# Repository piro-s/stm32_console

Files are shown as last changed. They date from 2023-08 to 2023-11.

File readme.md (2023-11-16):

## STM32 Console  
At the beginning it was a game console project on STM32, but then I found out 
about Anbernic devices. Now this is a debugging device for STM32F103Cx 
microcontrollers (STM32F103C6, C8, CB, maybe C4, but too little memory).  
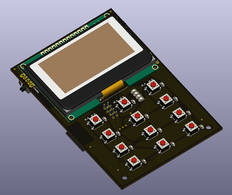
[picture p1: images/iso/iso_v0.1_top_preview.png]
iso_v0.1_top
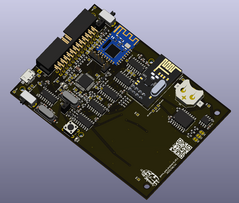
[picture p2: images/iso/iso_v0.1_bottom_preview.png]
iso_v0.1_bottom
   

---
The console has:  
+ display;  
+ buttons;  
+ temperature sensor LM75B;  
+ RTC module DS3231M;  
+ 4 LEDs;  
+ vibration motor;  
+ external speaker;  
+ radio module NRF24L01;  
+ bluetooth module JDY-23;  
+ interface converters: RS-232, RS-485 (with terminator 120 Ohm), USB-UART.  

---
The external connector gives access to connect:  
+ 4 digital inputs/outputs;  
+ 2 PWM outputs;  
+ 1 analog input (max 6V, if you need more, connect a resistor in series, see the scheme for details);  
+ SPI, I2C, UART;  
+ RS-232, RS-485.  

Pinout (IDC-26M):  
| Pin | Name | Description |
|-----|---|---|
| 1 | 5V | Output from TP5400 |
| 2 | Vdd | From usb or for power input |
| 3 | 3.3V | Output from AMS1117 |
| 4 | 5V | Output from TP5400 |
| 5 | Analog input  | Max 6V, or use resistor for increase voltage divider |
| 6 | PWM2 | PWM output or GPIO PORTB.9, limited 1k Ohm |
| 7 | GPIO PORTA.12 | Limited 1k Ohm |
| 8 | PWM1 | PWM output or GPIO PORTB.8, limited 1k Ohm |
| 9 | GPIO PORTA.11 | Limited 1k Ohm |
| 10  | SPI CS | To connect an external device or GPIO PORTB.12, limited 1k Ohm |
| 11  | GPIO PORTA.10 | Limited 1k Ohm |
| 12  | SPI MOSI | |
| 13  | GPIO PORTA.9  | Limited 1k Ohm |
| 14  | SPI SCK | |
| 15  | SPI MISO | |
| 16  | Data+ | Noninverting Receiver Input A / Driver Output A (for MOXA Data-) |
| 17  | I2C SCL | |
| 18  | Data- | Inverting Receiver Input B / Driver Output B (for MOXA Data+) |
| 19  | I2C SDA | |
| 20  | GND | |
| 21  | UART RX | Also connect to driver RS-485 and USB |
| 22  | UART TX | Also connect to driver RS-485 and USB |
| 23  | RS-232 RX | |
| 24  | RS-232 TX | |
| 25  | GND | |
| 26  | GND | |

---
#### Scheme:  
[Scheme_v0.1](docs/game_pad_keyboard_v0.1.pdf)  

#### PCB:  
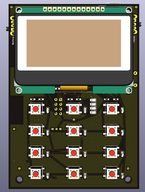
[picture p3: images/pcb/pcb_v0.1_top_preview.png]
pcb_v0.1_top
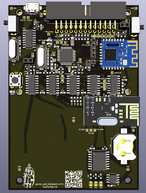
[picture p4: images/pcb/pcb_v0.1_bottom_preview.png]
pcb_v0.1_bottom
   

#### Gerber:  
Archive for production:  
[gerber_v0.1](https://github.com/piro-s/stm32_console/raw/master/gerber/game_pad_keyboard_v0.1.zip)

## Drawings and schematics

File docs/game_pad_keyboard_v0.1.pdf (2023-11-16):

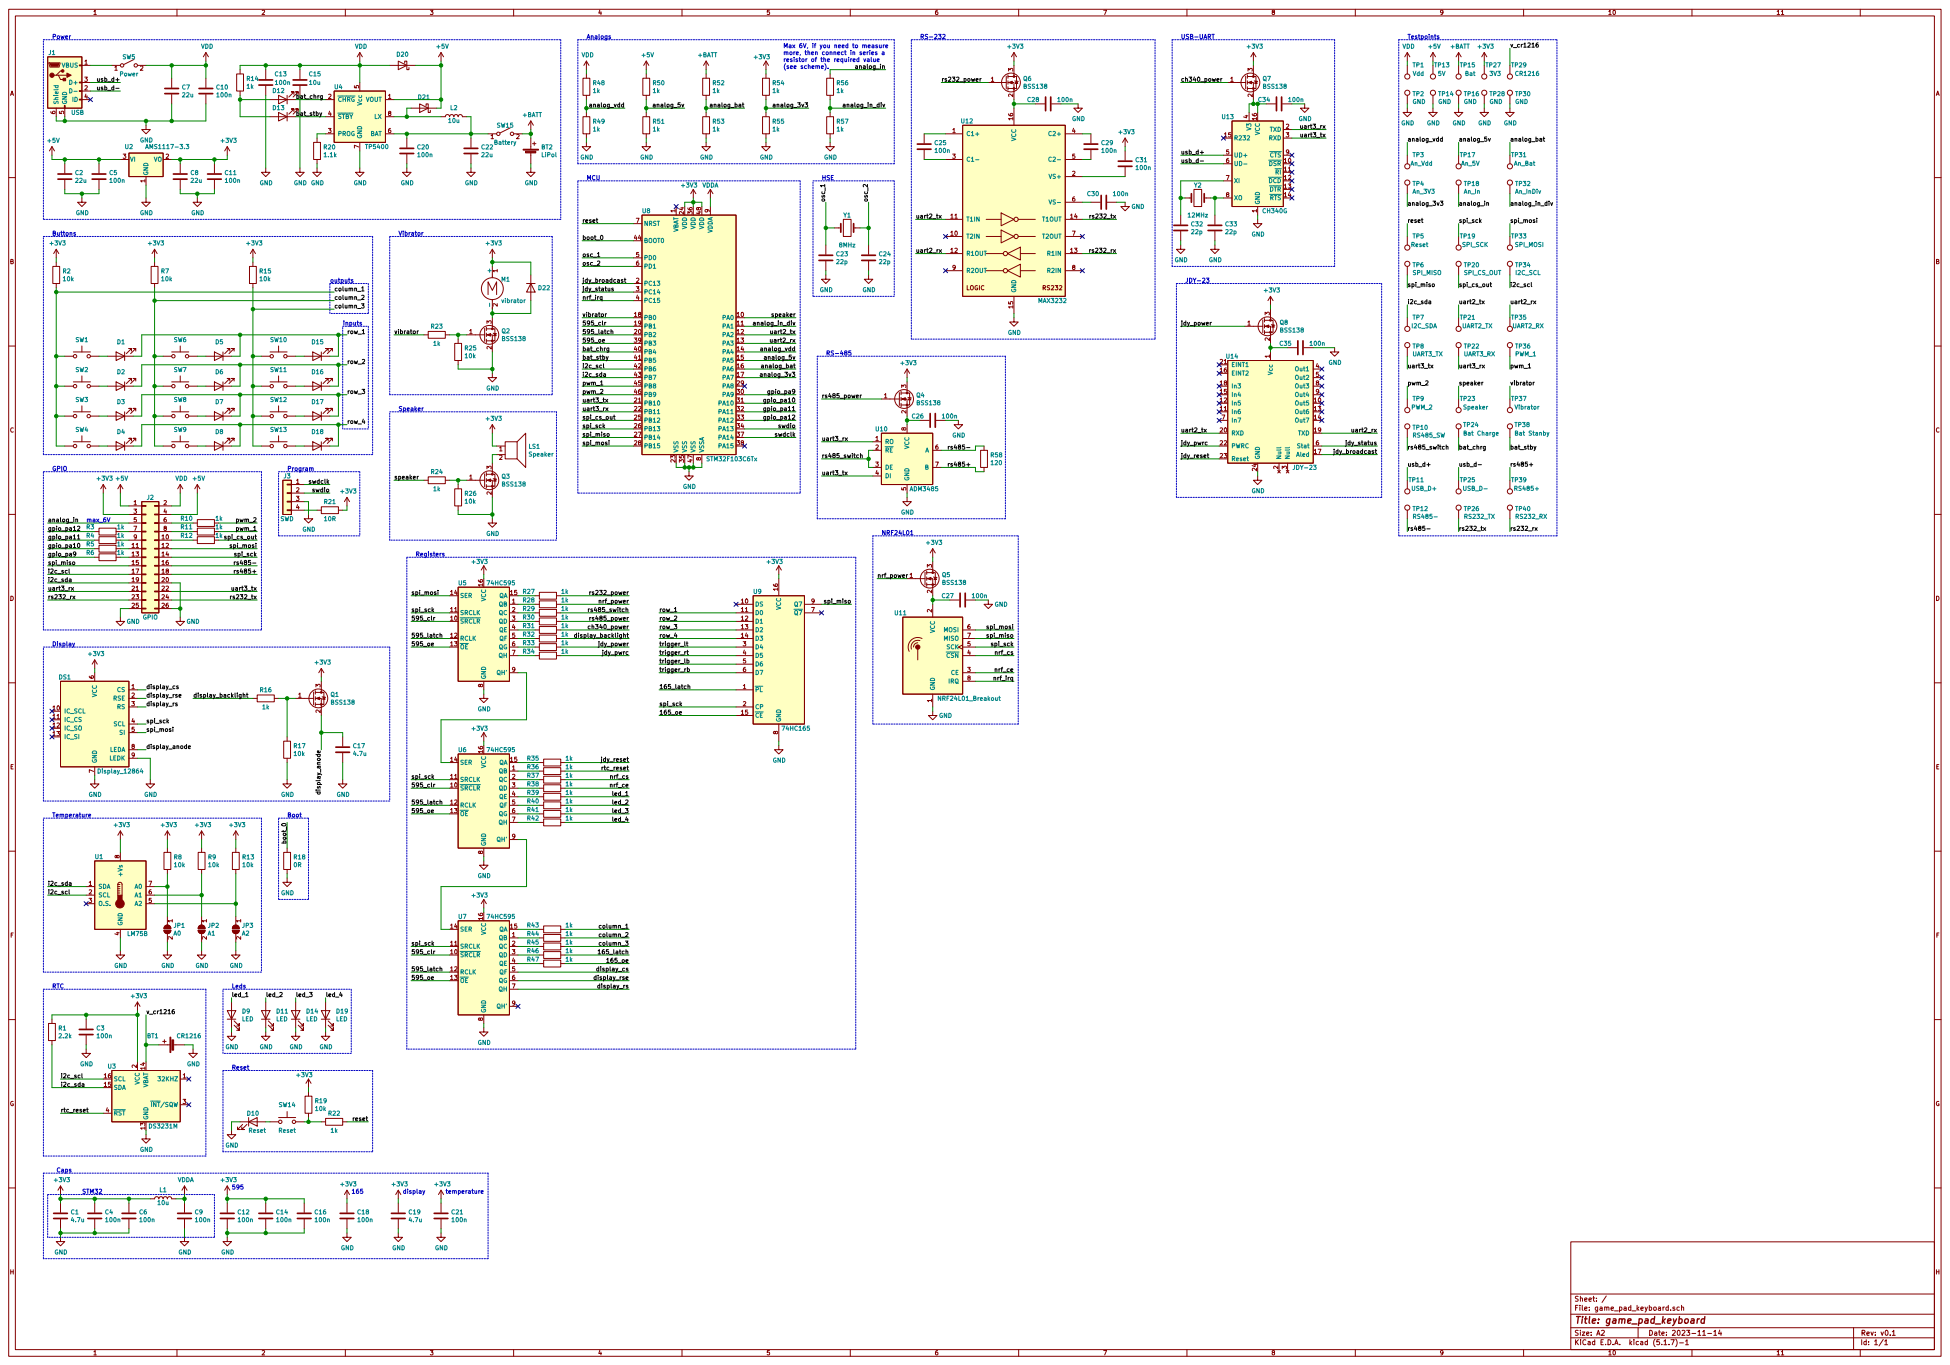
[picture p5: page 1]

Max 6V, if you need to measure more, then connect in series a resistor of the required value

1 VDD 24 VDD 36 VDD 48 VDDA

9 VSS 23 VSS 35 VSS 47 VSSA

8 QH' 9 U7 74HC595 PL 1 DS 10 D0 11 D1 12 D2 13 D3 14 CE 15 VCC 16 CP 2 D4 3 D5 4 D6 5 D7 6 Q7 7 GND

2 CE 3 CSN 4 SCK 5 MOSI 6 MISO 7

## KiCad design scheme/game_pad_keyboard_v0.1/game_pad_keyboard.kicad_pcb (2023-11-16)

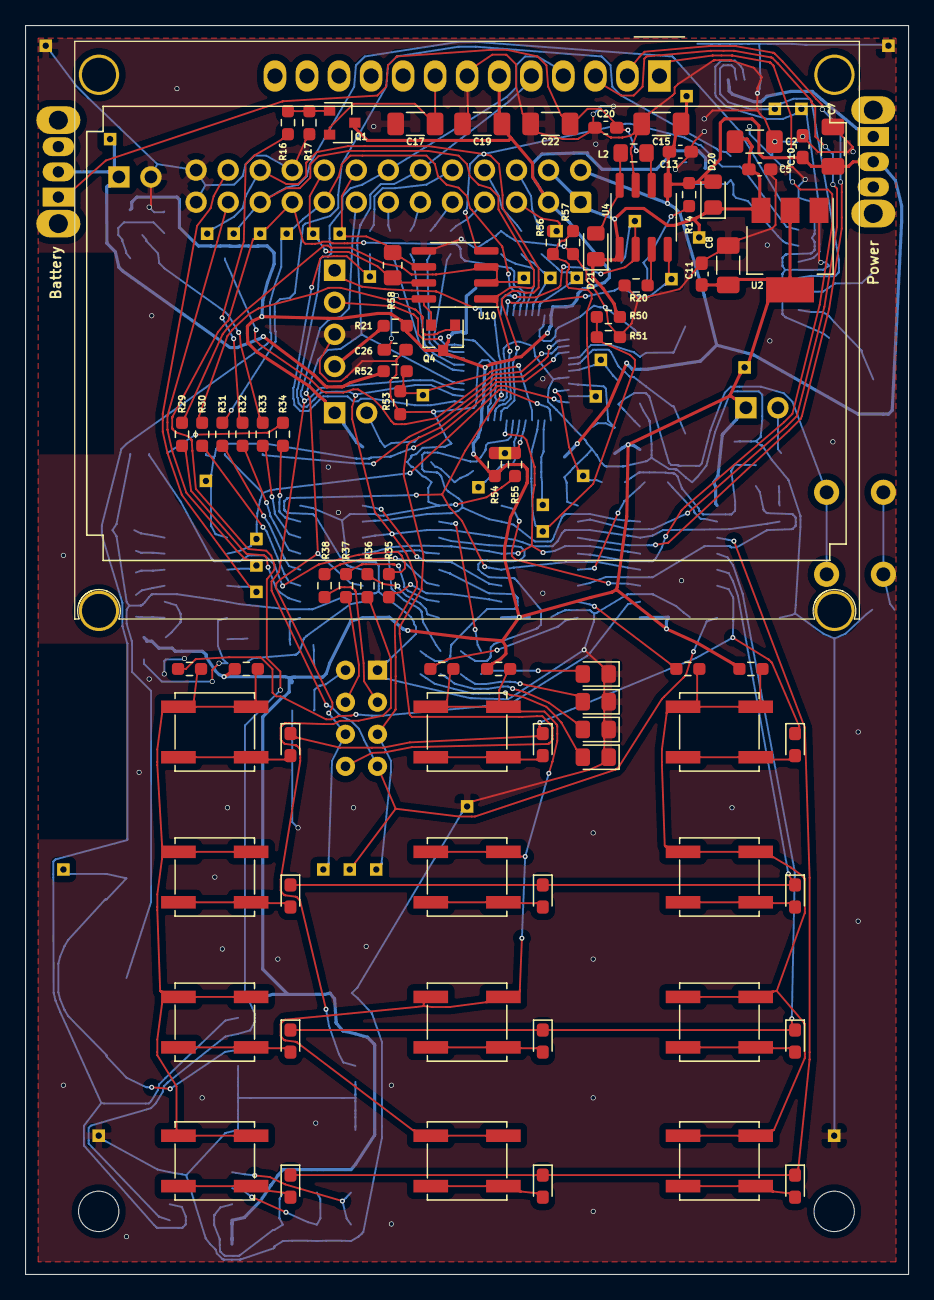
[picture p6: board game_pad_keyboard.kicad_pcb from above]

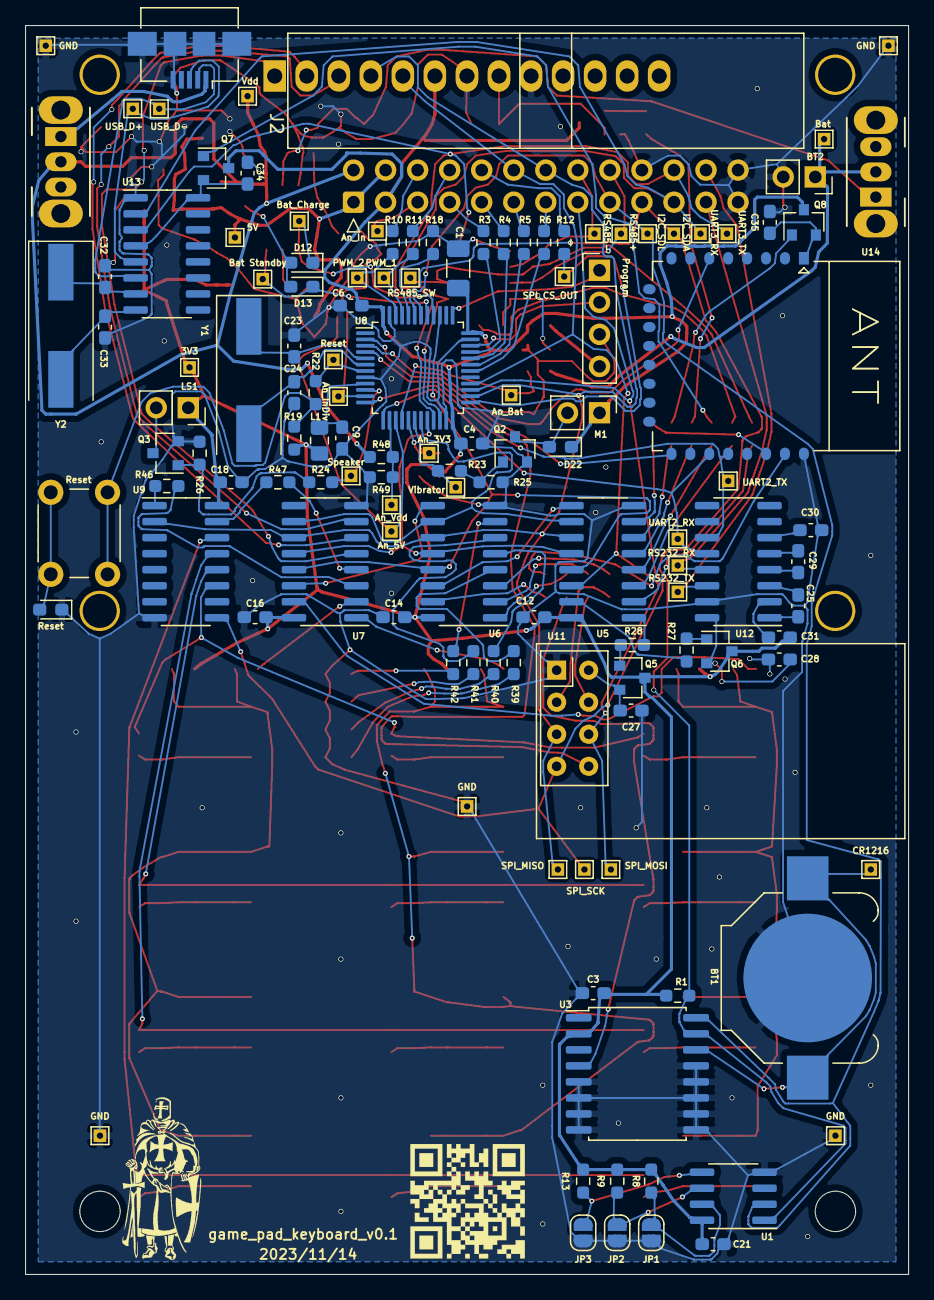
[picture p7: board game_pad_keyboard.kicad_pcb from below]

Board: 2 copper layers, 70.0 x 99.0 mm, 207 parts (127 on the bottom side), 151 nets.

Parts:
BT1: CR1216; BatteryHolder_Keystone_3000_1x12mm
BT2: LiPol; PinSocket_1x02_P2.54mm_Vertical
C1, C17, C19: 4.7u; C_1206_3216Metric_Pad1.33x1.80mm_HandSolder
C2, C7, C8, C22: 22u; C_1206_3216Metric_Pad1.33x1.80mm_HandSolder
C3, C4, C5, C6, C9, C10, C11, C12, C13, C14, C16, C18, C20, C21, C25, C26, C27, C28, C29, C30, C31, C34, C35: 100n; C_0603_1608Metric_Pad1.08x0.95mm_HandSolder
C15: 10u; C_1206_3216Metric_Pad1.33x1.80mm_HandSolder
C23, C24, C32, C33: 22p; C_0603_1608Metric_Pad1.08x0.95mm_HandSolder
D1, D2, D3, D4, D5, D6, D7, D8, D12, D13, D15, D16, D17, D18: LED; LED_0603_1608Metric_Pad1.05x0.95mm_HandSolder
D9, D11, D14, D19: LED; LED_0805_2012Metric_Pad1.15x1.40mm_HandSolder
D10: Reset; LED_0603_1608Metric_Pad1.05x0.95mm_HandSolder
D20, D21: D_Schottky; D_0805_2012Metric_Pad1.15x1.40mm_HandSolder
D22: D; D_0603_1608Metric_Pad1.05x0.95mm_HandSolder
DS1: Display_12864
J1: USB; USB_Micro-B_Amphenol_10104110_Horizontal
J2: GPIO; IDC-Header_2x13_P2.54mm_Horizontal
J3: SWD; PinHeader_1x04_P2.54mm_Vertical
JP1: A0; SolderJumper-2_P1.3mm_Open_RoundedPad1.0x1.5mm
JP2: A1; SolderJumper-2_P1.3mm_Open_RoundedPad1.0x1.5mm
JP3: A2; SolderJumper-2_P1.3mm_Open_RoundedPad1.0x1.5mm
L1, L2: 10u; L_0805_2012Metric_Pad1.15x1.40mm_HandSolder
LS1: Speaker; PinSocket_1x02_P2.54mm_Vertical
M1: vibrator; PinHeader_1x02_P2.54mm_Vertical
Q1, Q2, Q3, Q4, Q5, Q6, Q7, Q8: BSS138; SOT-23
R1: 2.2k; R_0603_1608Metric_Pad0.98x0.95mm_HandSolder
R2, R7, R8, R9, R13, R15, R17, R19, R25, R26: 10k; R_0603_1608Metric_Pad0.98x0.95mm_HandSolder
R3, R4, R5, R6, R10, R11, R12, R14, R16, R22, R23, R24, R27, R28, R29, R30, R31, R32, R33, R34, R35, R36, R37, R38, R39, R40, R41, R42, R43, R44, R45, R46, R47, R48, R49, R50, R51, R52, R53, R54, R55, R56, R57: 1k; R_0603_1608Metric_Pad0.98x0.95mm_HandSolder
R18: 0R; R_0603_1608Metric_Pad0.98x0.95mm_HandSolder
R20: 1.1k; R_0603_1608Metric_Pad0.98x0.95mm_HandSolder
R21: 10R; R_0603_1608Metric_Pad0.98x0.95mm_HandSolder
R58: 120; R_0805_2012Metric_Pad1.20x1.40mm_HandSolder
SW1, SW2, SW3, SW4, SW6, SW7, SW8, SW9, SW10, SW11, SW12, SW13: SW_Push; SW_SPST_EVPBF
SW5: Power; SW_CuK_OS102011MA1QN1_SPDT_Angled
SW14: Reset; SW_PUSH_6mm
SW15: Battery; SW_CuK_OS102011MA1QN1_SPDT_Angled
TP1: Vdd; TestPoint_THTPad_1.0x1.0mm_Drill0.5mm
TP2, TP14, TP16, TP28, TP30: GND; TestPoint_THTPad_1.0x1.0mm_Drill0.5mm
TP3: An_Vdd; TestPoint_THTPad_1.0x1.0mm_Drill0.5mm
TP4: An_3V3; TestPoint_THTPad_1.0x1.0mm_Drill0.5mm
TP5: Reset; TestPoint_THTPad_1.0x1.0mm_Drill0.5mm
TP6: SPI_MISO; TestPoint_THTPad_1.0x1.0mm_Drill0.5mm
TP7: I2C_SDA; TestPoint_THTPad_1.0x1.0mm_Drill0.5mm
TP8: UART3_TX; TestPoint_THTPad_1.0x1.0mm_Drill0.5mm
TP9: PWM_2; TestPoint_THTPad_1.0x1.0mm_Drill0.5mm
TP10: RS485_SW; TestPoint_THTPad_1.0x1.0mm_Drill0.5mm
TP11: USB_D+; TestPoint_THTPad_1.0x1.0mm_Drill0.5mm
TP12: RS485-; TestPoint_THTPad_1.0x1.0mm_Drill0.5mm
TP13: 5V; TestPoint_THTPad_1.0x1.0mm_Drill0.5mm
TP15: Bat; TestPoint_THTPad_1.0x1.0mm_Drill0.5mm
TP17: An_5V; TestPoint_THTPad_1.0x1.0mm_Drill0.5mm
TP18: An_In; TestPoint_THTPad_1.0x1.0mm_Drill0.5mm
TP19: SPI_SCK; TestPoint_THTPad_1.0x1.0mm_Drill0.5mm
TP20: SPI_CS_OUT; TestPoint_THTPad_1.0x1.0mm_Drill0.5mm
TP21: UART2_TX; TestPoint_THTPad_1.0x1.0mm_Drill0.5mm
TP22: UART3_RX; TestPoint_THTPad_1.0x1.0mm_Drill0.5mm
TP23: Speaker; TestPoint_THTPad_1.0x1.0mm_Drill0.5mm
TP24: Bat Charge; TestPoint_THTPad_1.0x1.0mm_Drill0.5mm
TP25: USB_D-; TestPoint_THTPad_1.0x1.0mm_Drill0.5mm
TP26: RS232_TX; TestPoint_THTPad_1.0x1.0mm_Drill0.5mm
TP27: 3V3; TestPoint_THTPad_1.0x1.0mm_Drill0.5mm
TP29: CR1216; TestPoint_THTPad_1.0x1.0mm_Drill0.5mm
TP31: An_Bat; TestPoint_THTPad_1.0x1.0mm_Drill0.5mm
TP32: An_InDiv; TestPoint_THTPad_1.0x1.0mm_Drill0.5mm
TP33: SPI_MOSI; TestPoint_THTPad_1.0x1.0mm_Drill0.5mm
TP34: I2C_SCL; TestPoint_THTPad_1.0x1.0mm_Drill0.5mm
TP35: UART2_RX; TestPoint_THTPad_1.0x1.0mm_Drill0.5mm
TP36: PWM_1; TestPoint_THTPad_1.0x1.0mm_Drill0.5mm
TP37: Vibrator; TestPoint_THTPad_1.0x1.0mm_Drill0.5mm
TP38: Bat Stanby; TestPoint_THTPad_1.0x1.0mm_Drill0.5mm
TP39: RS485+; TestPoint_THTPad_1.0x1.0mm_Drill0.5mm
TP40: RS232_RX; TestPoint_THTPad_1.0x1.0mm_Drill0.5mm
U1: LM75B; SOIC-8_3.9x4.9mm_P1.27mm
U2: AMS1117-3.3; SOT-223-3_TabPin2
U3: DS3231M; SOIC-16W_7.5x10.3mm_P1.27mm
U4: TP5400; SOP-8_3.76x4.96mm_P1.27mm
U5, U6, U7: 74HC595; SOIC-16_3.9x9.9mm_P1.27mm
U8: STM32F103C6Tx; LQFP-48_7x7mm_P0.5mm
U9: 74HC165; SOIC-16_3.9x9.9mm_P1.27mm
U10: ADM3485; SOIC-8_3.9x4.9mm_P1.27mm
U11: NRF24L01_Breakout; nRF24L01_Breakout
U12: MAX3232; SOIC-16_3.9x9.9mm_P1.27mm
U13: CH340G; SOIC-16_3.9x9.9mm_P1.27mm
U14: JDY-23
Y1: 8MHz; Crystal_SMD_HC49-SD
Y2: 12MHz; Crystal_SMD_HC49-SD

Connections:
+3V3: C1.1, C3.1, C4.1, C6.1, C8.1, C11.1, C12.1, C14.1, C16.1, C18.1, C19.1, C21.1, C31.1, D22.1, DS1.6, J2.3, L1.1, LS1.1, M1.1, Q1.3, Q4.3, Q5.3, Q6.3, Q7.3, Q8.3, R1.1, R2.1, R7.1, R8.1, R9.1, R13.1, R15.1, R19.1, R21.1, R54.1, TP27.1, U1.8, U2.2, U3.2, U5.16, U6.16, U7.16, U8.24, U8.36, U8.48, U9.16
+5V: C2.1, C5.1, D20.1, D21.1, J2.1, J2.4, R50.1, TP13.1, U2.3, U4.1
+BATT: BT2.1, R52.1, SW15.2, TP15.1
/165_latch: R46.1, U9.1
/165_oe: R47.1, U9.15
/595_clr: U5.10, U6.10, U7.10, U8.19
/595_latch: U5.12, U6.12, U7.12, U8.20
/595_oe: U5.13, U6.13, U7.13, U8.39
/analog_3v3: R54.2, R55.1, TP4.1, U8.17
/analog_5v: R50.2, R51.1, TP17.1, U8.15
/analog_bat: R52.2, R53.1, TP31.1, U8.16
/analog_in: J2.5, R56.1, TP18.1
/analog_in_div: R56.2, R57.1, TP32.1, U8.11
/analog_vdd: R48.2, R49.1, TP3.1, U8.14
/bat_chrg: D12.1, TP24.1, U4.2, U8.40
/bat_stby: D13.1, TP38.1, U4.4, U8.41
/boot_0: R18.1, U8.44
/ch340_power: Q7.1, R31.1
/column_1: R2.2, R43.1, SW1.1, SW2.1, SW3.1, SW4.1
/column_2: R7.2, R44.1, SW6.1, SW7.1, SW8.1, SW9.1
/column_3: R15.2, R45.1, SW10.1, SW11.1, SW12.1, SW13.1
/display_anode: C17.1, DS1.8, Q1.2
/display_backlight: R16.2, R32.1
/display_cs: DS1.1, U7.5
/display_rs: DS1.3, U7.7
/display_rse: DS1.2, U7.6
/gpio_pa9: R6.1, U8.30
/gpio_pa10: R5.1, U8.31
/gpio_pa11: R4.1, U8.32
/gpio_pa12: R3.1, U8.33
/i2c_scl: J2.17, TP34.1, U1.2, U3.16, U8.42
/i2c_sda: J2.19, R1.2, TP7.1, U1.1, U3.15, U8.43
/jdy_broadcast: U8.2, U14.17
/jdy_power: Q8.1, R33.1
/jdy_pwrc: R34.1, U14.22
/jdy_reset: R35.1, U14.23
/jdy_status: U8.3, U14.6
/led_1: D9.2, R39.1
/led_2: D11.2, R40.1
/led_3: D14.2, R41.1
/led_4: D19.2, R42.1
/nrf_ce: R38.1, U11.3
/nrf_cs: R37.1, U11.4
/nrf_irq: U8.4, U11.8
/nrf_power: Q5.1, R28.1
/osc_1: C23.1, U8.5, Y1.1
/osc_2: C24.1, U8.6, Y1.2
/pwm_1: R11.2, TP36.1, U8.45
/pwm_2: R10.2, TP9.1, U8.46
/reset: R22.1, TP5.1, U8.7
/row_1: D1.1, D5.1, D15.1, U9.11
/row_2: D2.1, D6.1, D16.1, U9.12
/row_3: D3.1, D7.1, D17.1, U9.13
/row_4: D4.1, D8.1, D18.1, U9.14
/rs232_power: Q6.1, R27.1
/rs232_rx: J2.23, TP40.1, U12.13
/rs232_tx: J2.24, TP26.1, U12.14
/rs485+: J2.18, R58.2, TP39.1, U10.7
/rs485-: J2.16, R58.1, TP12.1, U10.6
/rs485_power: Q4.1, R30.1
/rs485_switch: R29.1, TP10.1, U10.2, U10.3
/rtc_reset: R36.1, U3.4
/speaker: R24.2, TP23.1, U8.10
/spi_cs_out: R12.2, TP20.1, U8.25
/spi_miso: J2.15, TP6.1, U8.27, U9.9, U11.7
/spi_mosi: DS1.5, J2.12, TP33.1, U5.14, U8.28, U11.6
/spi_sck: DS1.4, J2.14, TP19.1, U5.11, U6.11, U7.11, U8.26, U9.2, U11.5
/swdclk: J3.1, U8.37
/swdio: J3.2, U8.34
/uart2_rx: TP35.1, U8.13, U12.12, U14.19
/uart2_tx: TP21.1, U8.12, U12.11, U14.20
/uart3_rx: J2.21, TP22.1, U8.22, U10.1, U13.2
/uart3_tx: J2.22, TP8.1, U8.21, U10.4, U13.3
/usb_d+: J1.3, TP11.1, U13.5
/usb_d-: J1.2, TP25.1, U13.6
/v_cr1216: BT1.1, TP29.1, U3.14
/vibrator: R23.2, TP37.1, U8.18
GND: BT1.2, BT2.2, C1.2, C2.2, C3.2, C4.2, C5.2, C6.2, C7.2, C8.2, C9.2, C10.2, C11.2, C12.2, C13.2, C14.2, C15.2, C16.2, C17.2, C18.2, C19.2, C20.2, C21.2, C22.2, C23.2, C24.2, C26.1, C27.1, C28.1, C30.1, C32.2, C33.2, C34.1, C35.1, D9.1, D10.1, D11.1, D14.1, D19.1, DS1.7, DS1.9, J1.5, J1.6, J2.20, J2.25, J2.26, J3.3, JP1.2, JP2.2, JP3.2, Q2.2, Q3.2, R17.2, R18.2, R20.2, R25.2, R26.2, R49.2, R51.2, R53.2, R55.2, R57.2, TP2.1, TP14.1, TP16.1, TP28.1, TP30.1, U1.4, U2.1, U3.5, U3.6, U3.7, U3.8, U3.9, U3.10, U3.11, U3.12, U3.13, U4.7, U5.8, U6.8, U7.8, U8.8, U8.23, U8.35, U8.47, U9.8, U10.5, U11.1, U12.15, U13.1, U14.24
unnamed: C20.1, C22.1, L2.2, SW15.1, U4.6
unnamed: C25.1, U12.1
unnamed: C25.2, U12.3
unnamed: C26.2, Q4.2, U10.8
unnamed: C27.2, Q5.2, U11.2
unnamed: C28.2, Q6.2, U12.16
unnamed: C29.1, U12.4
unnamed: C29.2, U12.5
unnamed: C30.2, U12.6
unnamed: C31.2, U12.2
unnamed: C32.1, U13.7, Y2.1
unnamed: C33.1, U13.8, Y2.2
unnamed: C34.2, Q7.2, U13.4, U13.16
unnamed: C35.2, Q8.2, U14.1
unnamed: D1.2, SW1.2
unnamed: D2.2, SW2.2
unnamed: D3.2, SW3.2
unnamed: D4.2, SW4.2
unnamed: D5.2, SW6.2
unnamed: D6.2, SW7.2
unnamed: D7.2, SW8.2
unnamed: D8.2, SW9.2
unnamed: D10.2, SW14.1
unnamed: D12.2, D13.2, R14.2
unnamed: D15.2, SW10.2
unnamed: D16.2, SW11.2
unnamed: D17.2, SW12.2
unnamed: D18.2, SW13.2
unnamed: D21.2, L2.1, U4.8
unnamed: D22.2, M1.2, Q2.3
unnamed: J1.1, SW5.1
unnamed: J2.6, R10.1
unnamed: J2.7, R3.2
unnamed: J2.8, R11.1
unnamed: J2.9, R4.2
unnamed: J2.10, R12.1
unnamed: J2.11, R5.2
unnamed: J2.13, R6.2
unnamed: J3.4, R21.2
unnamed: JP1.1, R8.2, U1.7
unnamed: JP2.1, R9.2, U1.6
unnamed: JP3.1, R13.2, U1.5
unnamed: LS1.2, Q3.3
unnamed: Q1.1, R16.1, R17.1
unnamed: Q2.1, R23.1, R25.1
unnamed: Q3.1, R24.1, R26.1
unnamed: R19.2, R22.2, SW14.2
unnamed: R20.1, U4.3
unnamed: R27.2, U5.15
unnamed: R28.2, U5.1
unnamed: R29.2, U5.2
unnamed: R30.2, U5.3
unnamed: R31.2, U5.4
unnamed: R32.2, U5.5
unnamed: R33.2, U5.6
unnamed: R34.2, U5.7
unnamed: R35.2, U6.15
unnamed: R36.2, U6.1
unnamed: R37.2, U6.2
unnamed: R38.2, U6.3
unnamed: R39.2, U6.4
unnamed: R40.2, U6.5
unnamed: R41.2, U6.6
unnamed: R42.2, U6.7
unnamed: R43.2, U7.15
unnamed: R44.2, U7.1
unnamed: R45.2, U7.2
unnamed: R46.2, U7.3
unnamed: R47.2, U7.4
unnamed: U5.9, U6.14
unnamed: U6.9, U7.14
VDD: C7.1, C10.1, C13.1, C15.1, D20.2, J2.2, R14.1, R48.1, SW5.2, TP1.1, U4.5
VDDA: C9.1, L1.2, U8.9

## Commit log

2023-08-22 fix: Gerber link
    Fixed link to gerber archieve.
2023-11-16 fix: Caps location
    Location of the capacitors has changed; they are
    now located after the transistors.
    [game_pad_keyboard.dsn, game_pad_keyboard.kicad_pcb, game_pad_keyboard.sch]
2023-11-16 new: Gerber file
    Add gerber with fix caps.
